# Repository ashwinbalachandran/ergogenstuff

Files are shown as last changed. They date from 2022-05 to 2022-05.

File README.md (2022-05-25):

# Summary

Just a repo to save any files related to the ergogen based keyboard I'm trying to build off of https://github.com/tapioki/cephalopoda/tree/main/Architeuthis%20dux

## Notes
The `adux_mod.yml` is not the exact yml that's in the image below, cause of the changes I made in Kicad.

## Changes from the original A.dux
- Changed footprint to `mx`
- Changed the spread and stagger for some columns
- Increased the size of the `raw` outline
- In Kicad
    - repositioned the `promicro` & `trrs` a little bit
    - randomly moved the "empty circles" to edges of the pcb
    - slightly changed the edges of the pcb

## Update - Final
Changes in https://github.com/ashwinbalachandran/ergogenstuff/pull/3

## Issues fixed
https://github.com/ashwinbalachandran/ergogenstuff/issues/1

## Images
Fixed all errors & warning thanks to @duckyb
### Final state


### Broken state - Pre fix?


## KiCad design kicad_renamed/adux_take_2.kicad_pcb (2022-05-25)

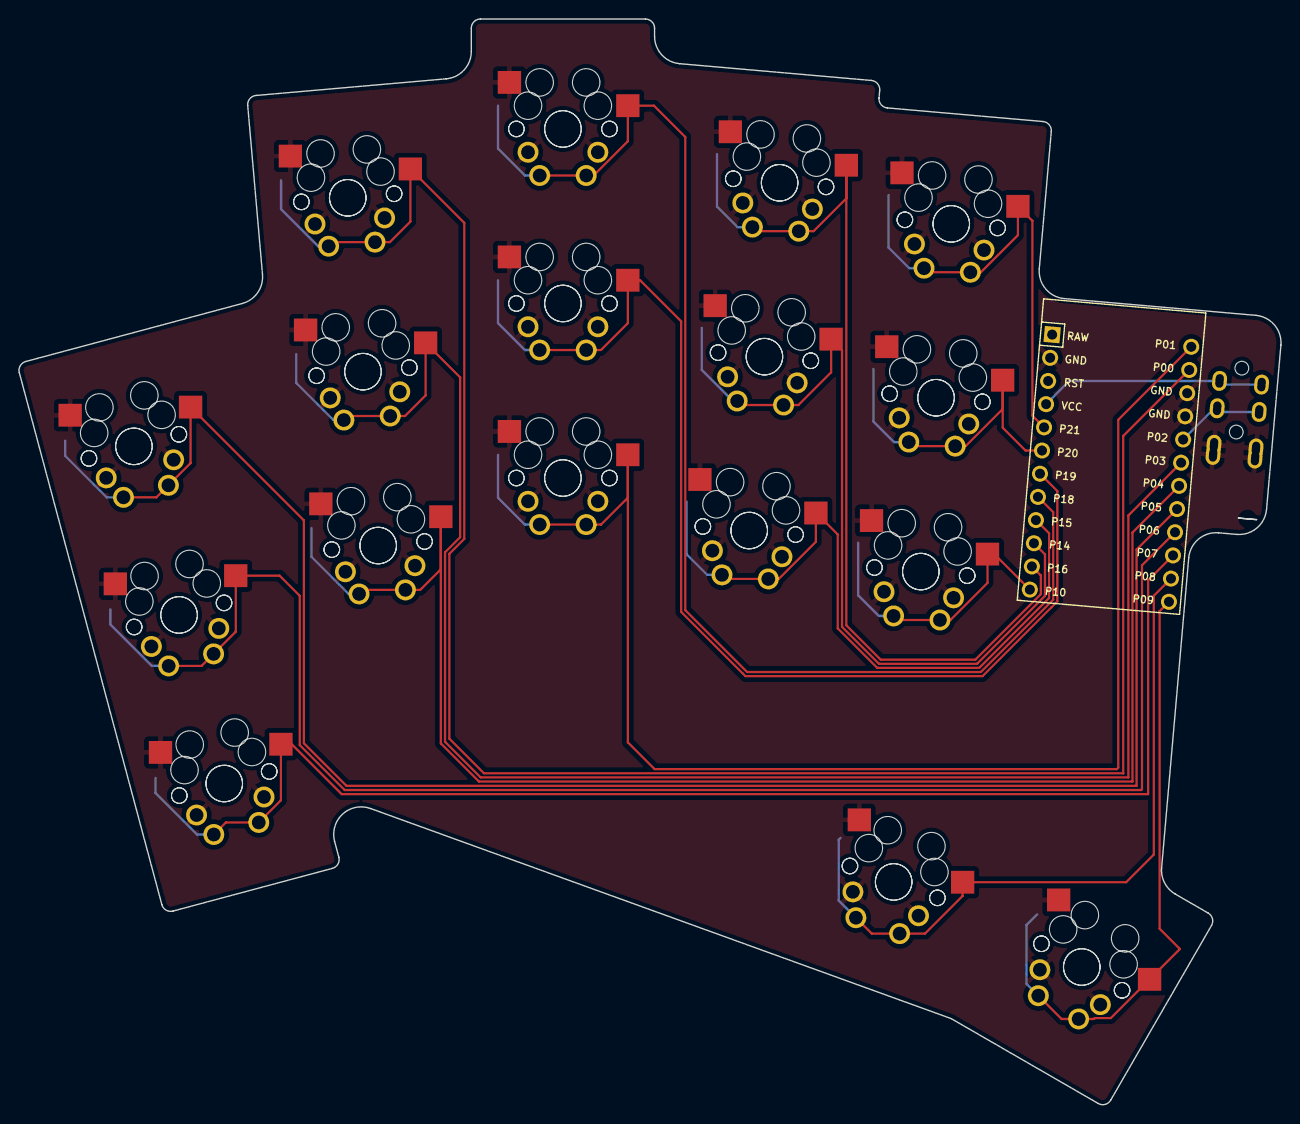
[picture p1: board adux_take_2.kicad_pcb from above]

Board: 2 copper layers, 137.7 x 118.5 mm, 35 parts (0 on the bottom side), 18 nets.

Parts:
MCU1: ProMicro
S1, S2, S3, S4, S5, S6, S7, S8, S9, S10, S11, S12, S13, S14, S15, S16, S17, S18, S19, S20, S21, S22, S23, S24, S25, S26, S27, S28, S29, S30, S31, S32, S33, S34: MX

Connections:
GND: MCU1.2, MCU1.15, MCU1.16, S1.2, S2.2, S3.2, S4.2, S5.2, S6.2, S7.2, S8.2, S9.2, S10.2, S11.2, S12.2, S13.2, S14.2, S15.2, S16.2, S17.2, S18.2, S19.2, S20.2, S21.2, S22.2, S23.2, S24.2, S25.2, S26.2, S27.2, S28.2, S29.2, S30.2, S31.2, S32.2, S33.2, S34.2
P0: MCU1.14, S11.1, S12.1
P1: MCU1.13, S13.1, S14.1
P3: MCU1.18, S9.1, S10.1
P4: MCU1.19, S7.1, S8.1
P5: MCU1.20, S5.1, S6.1
P6: MCU1.21, S3.1, S4.1
P7: MCU1.22, S1.1, S2.1
P8: MCU1.23, S31.1, S32.1
P9: MCU1.24, S33.1, S34.1
P10: MCU1.12, S25.1, S26.1
P14: MCU1.10, S21.1, S22.1
P15: MCU1.9, S19.1, S20.1
P16: MCU1.11, S23.1, S24.1
P18: MCU1.8, S17.1, S18.1
P19: MCU1.7, S15.1, S16.1
P20: MCU1.6, S27.1, S28.1
P21: MCU1.5, S29.1, S30.1

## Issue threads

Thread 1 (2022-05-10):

Design Review

duckyb, 2022-05-10:
I'm making this issue to report everything I see that you should fix about the design and give some tips on how to do it.

For reference, this is my work environment:
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

## Design Rule Checker

The first step is to run the DRC tool and see what issues appear. These things must all be fixed or at least adressed.
If you want to move the view on the problem you just need to click on the DRC issue and it will move your view inside the PCB editor.

### Tracks with unconnected ends

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

In this case, there is an overlap of some tracks that you need to fix. Just select and delete the extra track and re-route that bit correctly.

### Edge clearance violation

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

Here you have an extra circle inside your edge cuts layer. This circle overlaps a trace (the green one) so kicad complains.
I believe this circle is a mistake, in this case you should delete it.

### Drilled holes too close together

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

This is a problem in the setup of Kicad, usually the factories are able to create overlapping drill holes so you can remove this limitation in the PCB editor settings.

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

Just set to zero.

### Malformed outline

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

Pretty self-explanatory, why is there this circle in the board edge? I think you should delete it.

***

Here is how the board looks with zero errors:

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

duckyb, 2022-05-12:
@ashwinbalachandran ok. I'll have another look now that the board is possible to make, we can look if it makes sense from a user point of view

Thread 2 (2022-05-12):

Design review #2

duckyb, 2022-05-12:
Great, now the PCB is functional. Let's see if there are other issues.

## Switch pads

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

First tip I can give you is, think about what a switch does, it simply connects two points when pressed.
It does not matter which pad is what, you will still make the same connection.

What this means is that you can reverse the order of pad 1 and 2 of the switches every time you want.

You can use this to your advantage, by bringing all of the same pads close together, to make routing easier.

In your PCB you have the pins on opposite sides, in this footprint you see that all of the same pins are on the same side. (left/right)

[MX_solder&socket_reversible.zip](https://github.com/ashwinbalachandran/ergogenstuff/files/8682876/MX_solder.socket_reversible.zip)

## Ground plane

You can also add a fill zone for GND. This way you don't need to manually connect anything to it.

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

For example you can add a copper zone that covers the entirety of the PCB with these settings. After you fill the zone ("B" key) every GND pad will be connected.

## Switch spacing

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

You are not respecting the MX switch courtyards. The courtyard is the space you need to leave for the physical component that will go on the PCB.

For MX switches you need a 14x14mm spacing. If you don't use this the keycaps will hit each other. The spacing you are using at the moment is choc spacing, only suitable for choc switches.

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

You also have it on the thumb cluster, you need to separate the keys more.

ashwinbalachandran, 2022-05-19:
Hi @duckyb, so I managed to fix the first 2 issues, but I guess I should've done the last one first. When you mentioned that MX is supposed to be 14x14mm spacing what exactly does that mean?

is it center to center distance, if yes is there a way to measure or is the Kicad ruler approximate measurement enough?

duckyb, 2022-05-19:
If you edit a footprint value (select and press E) you will see x and y values.

Also you can see the square on the footprint. That's 14x14mm.

If the squares overlap then it's too close.

duckyb, 2022-05-20:
@ashwinbalachandran sorry I got confused and told you the wrong numbers.
```
standard MX cutout - 14×14mm (size of the switch)
distance between switches (center to center) - 19.05mm (both vertically and horizontally)
```

You need 19.05 between keys in order to avoid keycaps touching each other.
The suggestion to use the footprint outline as reference is still valid.

Try using a custom kicad grid size of `0.79375mm (19.05/24)` to place the switches, as suggested [here](https://wiki.ai03.com/books/pcb-design/page/pcb-guide-part-5---creating-the-pcb)

ashwinbalachandran, 2022-05-20:
Ohh ok that makes sense, i just measured one of my keycaps and realized it might be around 18/19mm just didnt know what exactly that measurement was.

I'll try changing that, thanks

ashwinbalachandran, 2022-05-21:
@duckyb I don't know if you can see my PR https://github.com/ashwinbalachandran/ergogenstuff/pull/3 but i basically did changes 2 & 3 also did 1 but it was so tedious to change each footprint. I used ergogen to generate the layout and bindings I think so those MX switches have the Pins and GND on opposite sides and each footprint was unique footprint.

duckyb, 2022-05-21:
@ashwinbalachandran looks like a fully functional PCB now.

Two things I notice are:

## 1)
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

JLC might ask you to increase the distance to at least 4 mm to avoid unwanted damage to the PCB in production. But what's the point of having a hole under the TRRS port anyway?

## 2)
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

This isn't really how I would rearrange the footprint but if you like it this way it works fine 😄

ashwinbalachandran, 2022-05-25:
Hi @duckyb thanks for all the help. Just wanted to clarify, I had originally changed the footprint but after I fixed the switch spacing it all got deleted since I manually edited every single footprint. After that I was just lazy to do it all again, I also moved the trrs & removed that circle under it.

Closed 2022-05-21.

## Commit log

2022-05-09 Adding Kicad files
    [Untitled-B_Cu.gbr, Untitled-B_Mask.gbr, Untitled-B_Paste.gbr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]
2022-05-12 Adding fixed pcb & gerbers
    [Untitled-B_Cu.gbr, Untitled-B_Mask.gbr, Untitled-B_Paste.gbr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]
2022-05-19 Manually fix pad order, add fill zone for GND
    [Untitled.kicad_pcb]
2022-05-21 Fresh project with MX spacing
    This reverts the pad order switches back to the ergogen default
    [adux_take_2-B_Cu.gbr, adux_take_2-B_Mask.gbr, adux_take_2-B_Paste.gbr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]
2022-05-25 Updated gerbers with spaced trrs jack
    [adux_take_2-B_Cu.gbr, adux_take_2-B_Mask.gbr, adux_take_2-B_Paste.gbr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]
2022-05-25 Updated pcb and project files
    Part of the trrs jack change
    [adux_take_2.kicad_pcb]
2022-05-25 Adding gerbers zip
